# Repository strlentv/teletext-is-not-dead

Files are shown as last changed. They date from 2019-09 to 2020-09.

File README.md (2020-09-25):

# Teletext is not dead
This is the source code of our demo for Function 2019, where it ended up on 3rd place in wild category. 
[You can find it on Pouet too.](http://www.pouet.net/prod.php?which=82943)

## What does it run on?
It runs on a custom hardware based on STM32F030F4, one of the cheapest microcontrollers, with an ARM Cortex-M0 CPU, 16k flash and 4k of RAM. To see the pictures and animation, connect its composite video output to a television AV-input and open teletext page 100.

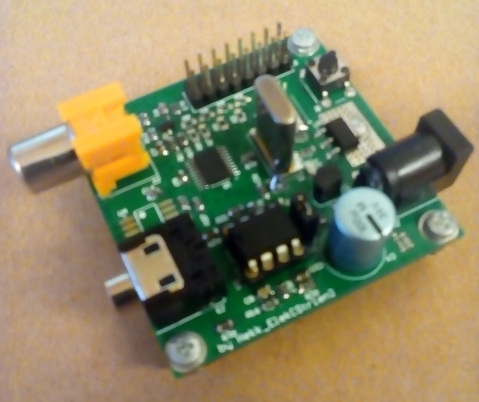
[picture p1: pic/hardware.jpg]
The hardware


## Theory of operation
Microcontrollers does not have any composite video output, let alone teletext output. Therefore some software magic was necessary: TIM3 runs in PWM mode and generates the video syncronization signal. Its duty cycle is updated in IT routine, so proper interlaced PAL syncronization is achieved. The teletext signal is then superimposed on the video signal by SPI1. SPI1 is fed by a DMA channel, however to achive proper timings, the DMA channel is configured by an another DMA channel which is triggered by TIM3.

## How do I build the hardware?
The gerber files are located at [hardware/fab](hardware/fab/DemoPlatform_Rev_A.rar). In the same directory you can find the [schematics](hardware/fab/DemoPlatform_Rev_A.pdf) too.
Some notes about assembly:
- Resistors with value "DNP" should not be placed (DNP==Do not place).
- The audio output and the EEPROM are not used, their assembly is optional.
- 13.875 MHz crystals are not common. Make sure you can source them.

The hardware was designed using Altium Designer 2011.

## How can I compile the software?
The demo is written in C and compiled using IAR Embedded Workbench for ARM 6.50. The final binary size is 15760 bytes.

Shout out to Gergely Vakulya, who made it compile with GCC. GCC project can be found [here](gcc/txt_gcc_make.tar.gz).

## Possible upgrades
- Sound is not yet implemented, but it is possible to use PWM output as a poor-man's audio DAC.
- With proper resistor values, it is possible to generate low-resolution 16-level grayscale images on the video output.
- The I2C EEPROM can be used to store demo-related data up to 128kbytes.
- It is possible to add a daughterboard to P1.

## Any remarks?
Feel free to reuse the hardware and the drivers to make teletext demos :)

## Credits
- Hardware and code by Hekk_Elek
- Teletext pages and music by And/or
- 3D graphics by Alex
- Voice by Brett

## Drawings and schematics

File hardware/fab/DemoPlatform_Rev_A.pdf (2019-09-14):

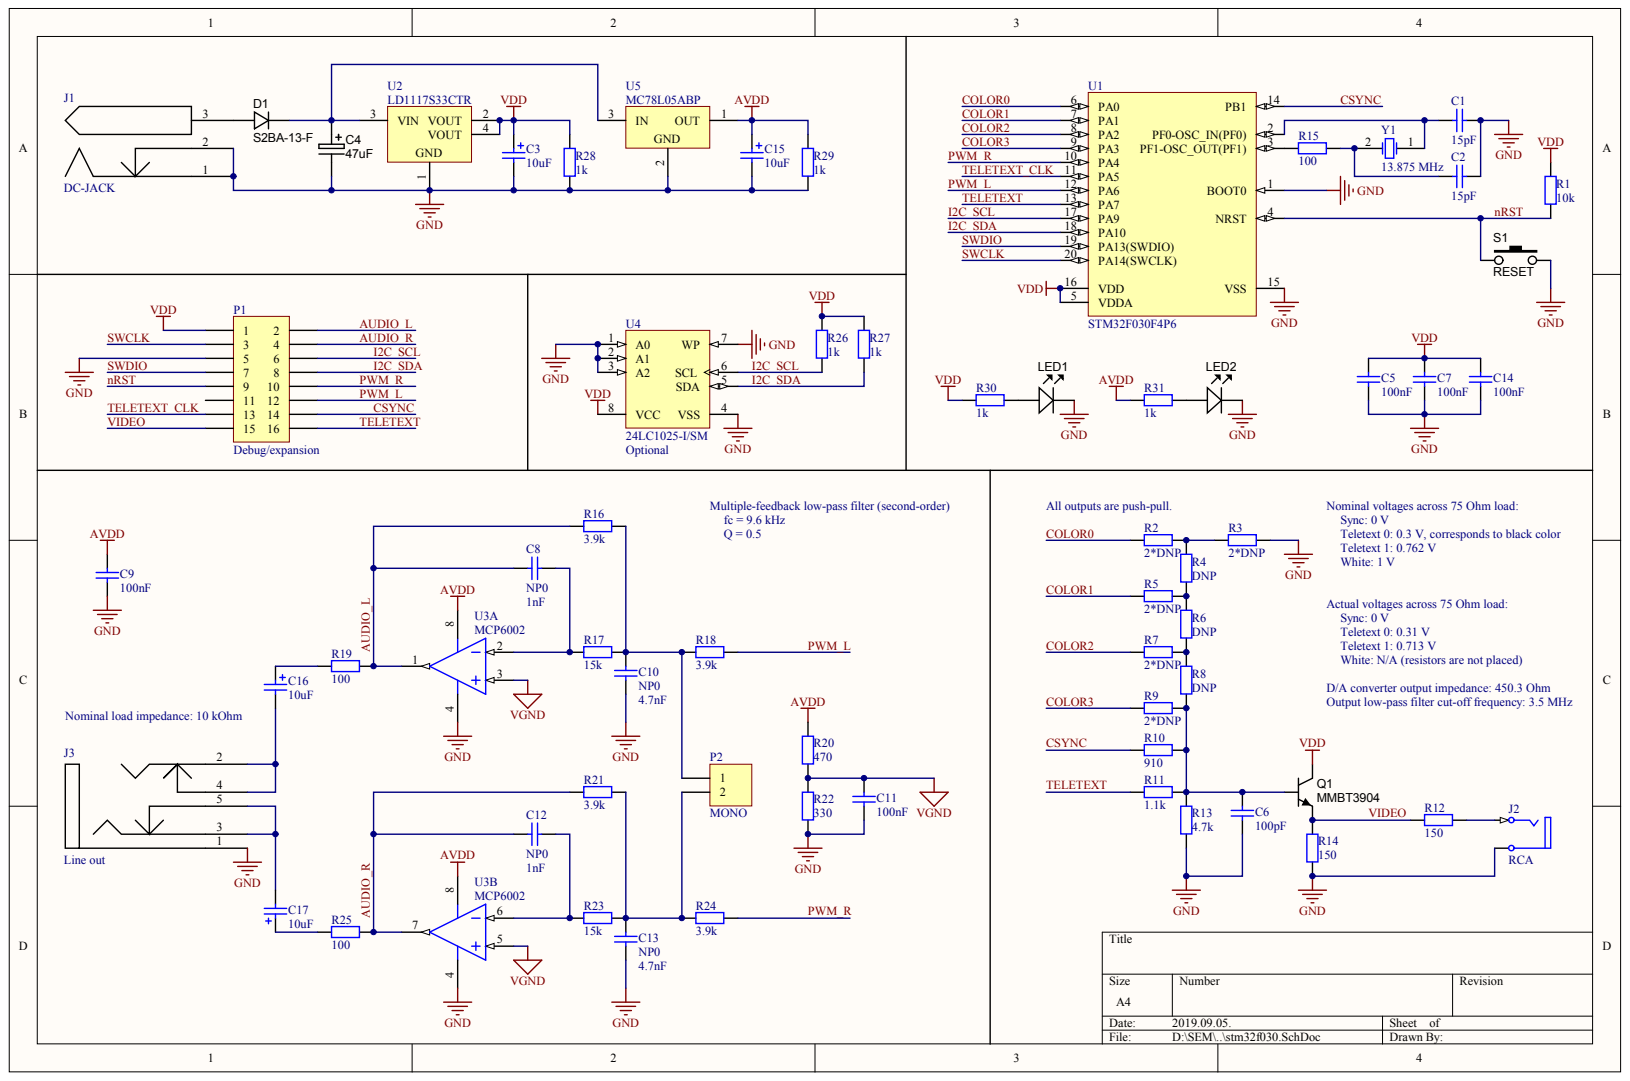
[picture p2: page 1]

Multiple-feedback low-pass filter (second-order)
fc = 9.6 kHz

All outputs are push-pull.

Nominal voltages across 75 Ohm load:
Sync: 0 V
Teletext 0: 0.3 V, corresponds to black color
Teletext 1: 0.762 V
White: 1 V

Actual voltages across 75 Ohm load:
Teletext 0: 0.31 V
Teletext 1: 0.713 V
White: N/A (resistors are not placed)

D/A converter output impedance: 450.3 Ohm
Output low-pass filter cut-off frequency: 3.5 MHz

Nominal load impedance: 10 kOhm

Comment | Description | Designator | Footprint | LibRef | Quantity
Cap | Capacitor | C1, C2, C5, C6, C7, C9, C11, C14 | CAPC2012X135N | Cap | 8
Cap Pol2 | Polarized Capacitor (Axial) | C3, C15, C16, C17 | CAPMP3528X210N | Cap Pol2_1 | 4
47uF | Capacitor THT Alum Elec 33uF 20% 200V | C4 | CAPE5.0mm | CAPE_33u_200V_THT | 1
NP0 | Capacitor | C8, C10, C12, C13 | CAPC2012X135N | Cap | 4
100V; 1.5A | Diode SMD 100V 1.5A SMA | D1 | DO-214AC | DIODE_100V_1.5A_SM A | 1
DC-JACK | Tápcsatlakozó | J1 | JACK | DC-JACK | 1
RCA | RCA Phono Jack, Right Angle, Thru-Hole, Snap-In | J2 | RCA/ 4.5-H2 | RCA | 1
Line out | Sztereo audio csatlakozó 3,5 mm | J3 | STEREO JACK 3.5 mm | STEREO JACK | 1
| LED 0805 SMD Green 12mcd 569nm | LED1, LED2 | LED-0805-K | LED_SMD_Green_0805 _12mcd | 2
Debug/ expansion | Header, 8-Pin, Dual row | P1 | HDR2X8 | Header 8X2 | 1
MONO | Header, 2-Pin | P2 | HDR1X2 | Header 2 | 1
NPN_MMBT3904 | Transistor SMD NPN 40V 0.2A 250mW SOT-23 | Q1 | SOT23-3 | NPN_MMBT3904 | 1
Res2 | Resistor | R1, R2, R3, R4, R5, R6, R7, R8, R9, R10, R11, R12, R13, R14, R15, R16, R17, R18, R19, R20, R21, R22, R23, R24, R25, R26, R27, R28, R29, R30, R31 | RESC2012X70N | Res2 | 31
RESET | Switch, tact, 5.0mm stem | S1 | TACT-SWITCH-TC-37XB | SW_THT_PB_5.0mm | 1
STM32F030F4P6 | ARM Cortex-M0 32-bit MCU, 16 KB Flash, 4 KB Internal RAM, 15 I/Os, 20-pin TSSOP, -40 to 85 degC, Tube | U1 | STM-TSSOP20_N | STM32F030F4P6 | 1
LD1117S33CTR | Fixed Low Drop Positive Voltage Regulator, 3.3V, 4-Pin SOT-223, Tape and Reel | U2 | SOT-223_M | LD1117S33CTR | 1
MCP6002 | Wide Bandwidth Dual JFET Input Operational Amplifier, 8-pin MDIP | U3 | N08E | TL082CP | 1
24LC1025-I/SM | 1 Mbit, 400kHz, 2.5V, I2C Serial EEPROM, 8-Pin SOIC 208mil, Industrial Temperature | U4 | SOIJ-SM8_M | 24LC1025-I/SM | 1
MC78L05ABP | Three-Terminal Low Current Positive Voltage Regulator | U5 | 29-04 | MC78L05ABP | 1
13.875 MHz | Crystal Oscillator | Y1 | HC-49U | ECS-10-13-1 | 1

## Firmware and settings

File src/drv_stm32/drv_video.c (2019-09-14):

/*! *******************************************************************************************************
* Copyright (c) 2018-2019 K. Sz. Horvath
*
* All rights reserved
*
* \file drv_video.c
*
* \brief Low-level video driver for STM32
*
* \author K. Sz. Horvath
*
**********************************************************************************************************/

//--------------------------------------------------------------------------------------------------------/
// Include files
//--------------------------------------------------------------------------------------------------------/
#include <string.h>
#include "types.h"
#include "consts.h"
#include "video.h"
#include "teletext.h"

// Drivers
#include "tim.h"
#include "dma.h"
#include "spi.h"
#include "main.h"

// Own include
#include "drv_video.h"

//--------------------------------------------------------------------------------------------------------/
// Definitions
//--------------------------------------------------------------------------------------------------------/
// Hardware used for SYNC generation
#define SYNC_TIMER    TIM3                            //!< Timer used for time base
#define SET_SYNCTIMER_PWM(x)  (SYNC_TIMER->CCR4 = x)  //!< This macro used for modifying PWM value on Channel 4

// Hardware register values -- 27.75 MHz clock input
#define NORMAL_LINE     (1776u)  //!< 64 usec long scanline
#define SHORT_LINE      (888u)   //!< 32 usec long half scanline (used at VSYNC)
#define NORMAL_SYNC     (131u)   //!< 4.7 usec long (normal) sync pulse at the beginning of the line
#define SHORT_SYNC      (65u)    //!< 2.35 usec long (short) sync pulse at the beginning of the line
#define LONG_SYNC       (757u)   //!< 27.3 usec long sync pulse at the beginning of the line
//#define TXT_START       (280u)   //!< ~10 usec after the falling edge of sync, teletext data will be displayed
//#define TXT_STOP        (1777u)  //!< No teletext data will be displayed

/*
// Hardware register values -- 48 MHz clock input
#define NORMAL_LINE     (3072u)  //!< 64 usec long line
#define SHORT_LINE      (1536u)  //!< 32 usec long line
#define NORMAL_SYNC     (192u)   //!< 4 usec long sync pulse at the beginning of the line
#define SHORT_SYNC      (96u)    //!< 2 usec long sync pulse at the beginning of the line
#define LONG_SYNC       (1440u)  //!< 30 usec long sync pulse at the beginning of the line
#define TXT_START       (480u)   //!< 10 usec after the falling edge of sync, teletext data will be displayed
#define TXT_STOP        (U16MAX) //!< No teletext data will be displayed
*/

//--------------------------------------------------------------------------------------------------------/
// Types
//--------------------------------------------------------------------------------------------------------/


//--------------------------------------------------------------------------------------------------------/
// Global variables
//--------------------------------------------------------------------------------------------------------/
#ifdef DEBUG
__root volatile DMA_Channel_TypeDef *pDMACH3 = (DMA_Channel_TypeDef*)DMA1_Channel3_BASE;
__root volatile TIM_TypeDef *pTIM3 = (TIM_TypeDef *)TIM3;
#endif

#ifdef PICTURE_OUTPUT
//! \brief Line buffer used by DMA to push pixels out
//! \note  Uses double-buffering (hence the 2); the +1 byte at the end is the horizontal blanking!
_Pragma("data_alignment=16") volatile static U8 gau8LineBuffer[ 2u ][ HORIZONTAL_RESOLUTION+1u ];
#endif

//! \brief Row counter for displaying the correct number of lines
volatile static U16 gu16RowCounter;

//! \brief Helper variable for re-enabling DMA
_Pragma("data_alignment=4") volatile U32 gcu32DmaEnable;


//--------------------------------------------------------------------------------------------------------/
// Static function declarations
//--------------------------------------------------------------------------------------------------------/


//--------------------------------------------------------------------------------------------------------/
// Static functions
//--------------------------------------------------------------------------------------------------------/
/*! *******************************************************************
 * \brief
 * \param
 * \return
 *********************************************************************/

 /*! *******************************************************************
 * \brief
 * \param
 * \return
 *********************************************************************/


//--------------------------------------------------------------------------------------------------------/
// Interface functions
//--------------------------------------------------------------------------------------------------------/
 /*! *******************************************************************
 * \brief  Init function
 * \param  -
 * \return -
 *********************************************************************/
void DrvVideo_Init( void )
{
  // Global variables init
#ifdef PICTURE_OUTPUT
  (void)memset( (U8*)gau8LineBuffer, 0, sizeof( gau8LineBuffer ) );  // note: black is represented by 0
#endif
  gu16RowCounter = 0u;
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
